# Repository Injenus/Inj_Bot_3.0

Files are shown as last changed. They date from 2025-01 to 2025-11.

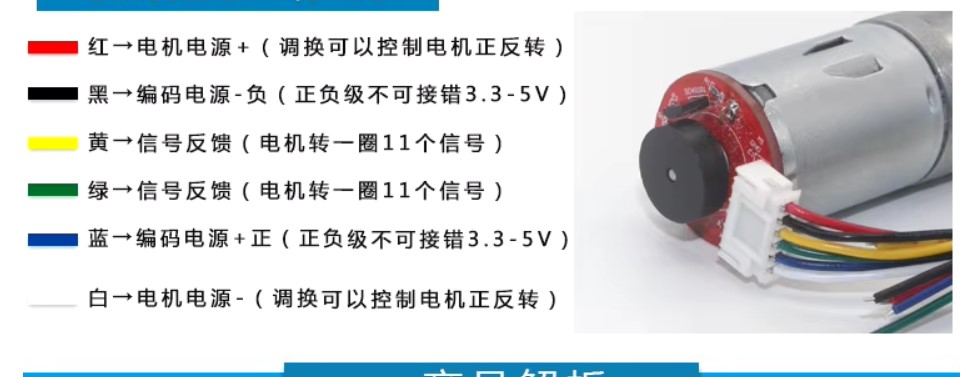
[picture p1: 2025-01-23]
chinese_motor.jpg

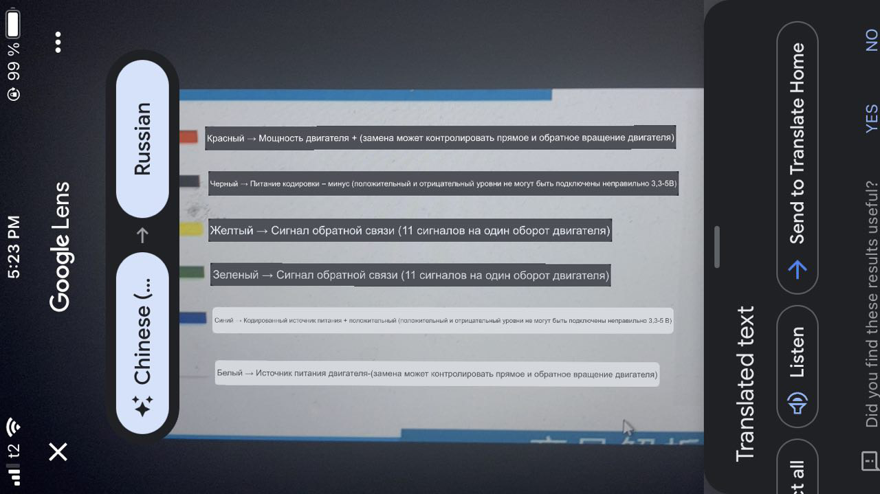
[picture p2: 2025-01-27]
trans_chinese_motor.jpg

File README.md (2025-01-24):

## Автономоный мобильный робот Inj Bot 3.0

### Имеет:
- ~~всех;~~
- манипулятор с 4-я степенями свободы;
- основную бинокулярную камеру с двумя степенями свободы;
- вспомогательную камеру на схвате манипулятора;
- лидар с регулируемой плоскостью положения;
- 7" экран для взаимодействия с человеком.<br/><br/>
### Фичи:
- Все вычисления производятся на борту согласно заложенной задаче.
- Запас хода не менее  минут, в среднем около  часов, в режиме ожидания - до  часов.<br/><br/>

### Железо:
- Raspberry Pi 5 с TPU ускорителем Google Coral.
- STM32F401 в качестве драйвера двигателей.
- Arduino Nano в качестве драйвера манипулятора.<br/><br/>

### Софт:
- ROS2.
- Кастомные пакеты для управления скоростью движения робота, положением манипулятора, обработке данных лидара и камер.

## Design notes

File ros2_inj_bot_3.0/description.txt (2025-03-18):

1. Пакет взаимодейсвтия с драйвером сервоприводов (servo):
    - отправка в ком-порт (send_com) данных из топика servo/to_write
    - получение из ком-порта (receive_com) и публикация в топик servo/current

2. Пакет взаимодейсвтия с камерами (camera):
    - получение потока с бинокулярной камеры (binocular_cam) и публикация в топик cam/binocular
    - получение потока с камеры на манипултяоре (arm_cam) и публикация в топик cam/arm

3. Пакет взаимодейсвтия с колёсами (wheel):
    - получение текущих об/мин с каждого колеса и публикация в топик wheel/current_rpm
    - чтение из топика wheel/target_rpm (об/мин) и отправка в ком-порт
        (получение и чтение данных реализовано в одном узле data_exchange - используется один uart канал)
            - для линейных и угловыйх скоростей используем стандратным протокол Twist,
            для обычных колёс имеем целевую линейную скрость и угловую по вепртикальной оси,
            которая представлет собой просто результат ПИДа по текущей ошибке
            - контроль об/мин колёс происходит на драйвере, но инф-цию об актуальных об/мин всё равно переылаем

4. Пакет для rplidar от разарботчиков (sllidar_ros2):
    - получение данных от лидара (rplidar c1) и публикация их в топик /scan

5. Пакет обработки данных лидара (lidar):
    - чтение данных из топика /scan
    - формирование моментальной карты, обработка зон интереса, публикация в топик lidar 
        (get_main_obstacles публикует медианные расстояния по заданному размеру сектора окружности)

6. Пакет для работы моделей ML (coral):
    - a hihuya tut ne budet, huy nastriosh ebuchiy coral

7. Пакет для ручного управления роботом (keyboard):
    - соотвутствующие узлы формируют уставки для колёс и целевые обобщённые координаты для камеры и маниулятора соответственно

8 - .. Пакеты для конкретных миссий.

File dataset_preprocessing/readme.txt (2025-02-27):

Аргументы cmd:
parser = argparse.ArgumentParser()
parser.add_argument("--src_dir", type=str, default="src_data", help="Исходная папка с данными")
parser.add_argument("--output_dir", type=str, default="augmented_data", help="Выходная папка")
parser.add_argument("--start_idx", type=int, default=0, help="Начальный индекс изображений")
parser.add_argument("--end_idx", type=int, default=None, help="Конечный индекс изображений")
args = parser.parse_args()

python run.py --src_dir src_data --output_dir augmented_data --start_idx 0 --end_idx 100

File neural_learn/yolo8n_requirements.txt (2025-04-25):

# Основные пакеты YOLO
ultralytics
torch
torchvision

# Обработка данных и изображений
numpy
pandas
opencv-python
Pillow
scikit-learn
scipy
imageio

# Визуализация и логирование
matplotlib
seaborn
tqdm

# Форматы данных и сериализация
PyYAML
tensorflow  # Для экспорта в TFLite

# Системные утилиты
psutil
py-cpuinfo
python-dotenv

# Сетевые и дополнительные зависимости
requests
prettytable
boto3
pandas-stubs

# Скрытые зависимости YOLO
pyqt5 # Для GUI
lap  # Для трекинга
thop  # Для FLOPs подсчета
triton  # Для некоторых оптимизаций
onnx  # Для экспорта моделей
onnxruntime  # Для инференса
protobuf # Для сериализации

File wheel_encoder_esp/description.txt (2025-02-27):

От контроллера (фактические скорости):
<S><speed_f_l><speed_f_l><speed_f_l><speed_f_l><speed_b_l><speed_b_l><speed_b_l><speed_b_l><speed_f_r><speed_f_r><speed_f_r><speed_f_r><speed_b_r><speed_b_r><speed_b_r><speed_b_r><SUM><SUM>
Последовательность сообщения:
    символ S
    4 байта float для скорости левого переднего колеса
    4 байта float для скорости левого заднего колеса
    4 байта float для скорости правого переднего колеса
    4 байта float для скорости правого заднего колеса
    2 байта контрольной суммы Флетчер-16

От хоста (целевые скорости):
<S><speed_f_l><speed_f_l><speed_f_l><speed_f_l><speed_b_l><speed_b_l><speed_b_l><speed_b_l><speed_f_r><speed_f_r><speed_f_r><speed_f_r><speed_b_r><speed_b_r><speed_b_r><speed_b_r><SUM><SUM>
Последовательность сообщения:
    символ S
    4 байта float для скорости левого переднего колеса
    4 байта float для скорости левого заднего колеса
    4 байта float для скорости правого переднего колеса
    4 байта float для скорости правого заднего колеса
    2 байта контрольной суммы Флетчер-16

отлично, теперь напиши для этого кода, чтобы он выводил в сериал не строку, а сами байты согласно протоколу:
<S><speed_f_l><speed_1><speed_1><speed_1><speed_1><speed_2><speed_2><speed_2><speed_2><speed_3><speed_3><speed_3><speed_3><speed_4><speed_4><speed_4><SUM><SUM>
Последовательность сообщения:
    символ S
    4 байта float для скорости левого переднего колеса
    4 байта float для скорости левого заднего колеса
    4 байта float для скорости правого переднего колеса
    4 байта float для скорости правого заднего колеса
    2 байта контрольной суммы Флетчер-16

да, нужно добавить вычисление конторльной суммы - для ВСЕХ байт до ней (включая и первый символ S)

здорово

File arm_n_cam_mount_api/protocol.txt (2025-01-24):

<A><angle0><angle0><angle1><angle1><angle2><angle2><angle3><angle3><angle4><angle4><angle5><angle5><angle6><angle6><SUM><SUM>

первым идёт байт - ascii-символ A, 

затем 14 байт углов для каждой сервы (по два байта на одну серву, диапазон от 0 до 270),
	первые 5 - рука снизу вверх, послдение 2 - камера снизу вверх

затем двухбайтовая контрольная сумма всех байт (15 байт) по формуле Флетчер-16

Подробнее про порядок серв:
	0 - вращат. основание руки
	1 - нижнее звено руки
	2 - среднее звено руки
	3 - верхнее звено руки
	4 - схват руки
	5 - вращат. основание камеры
	6 - звено камеры

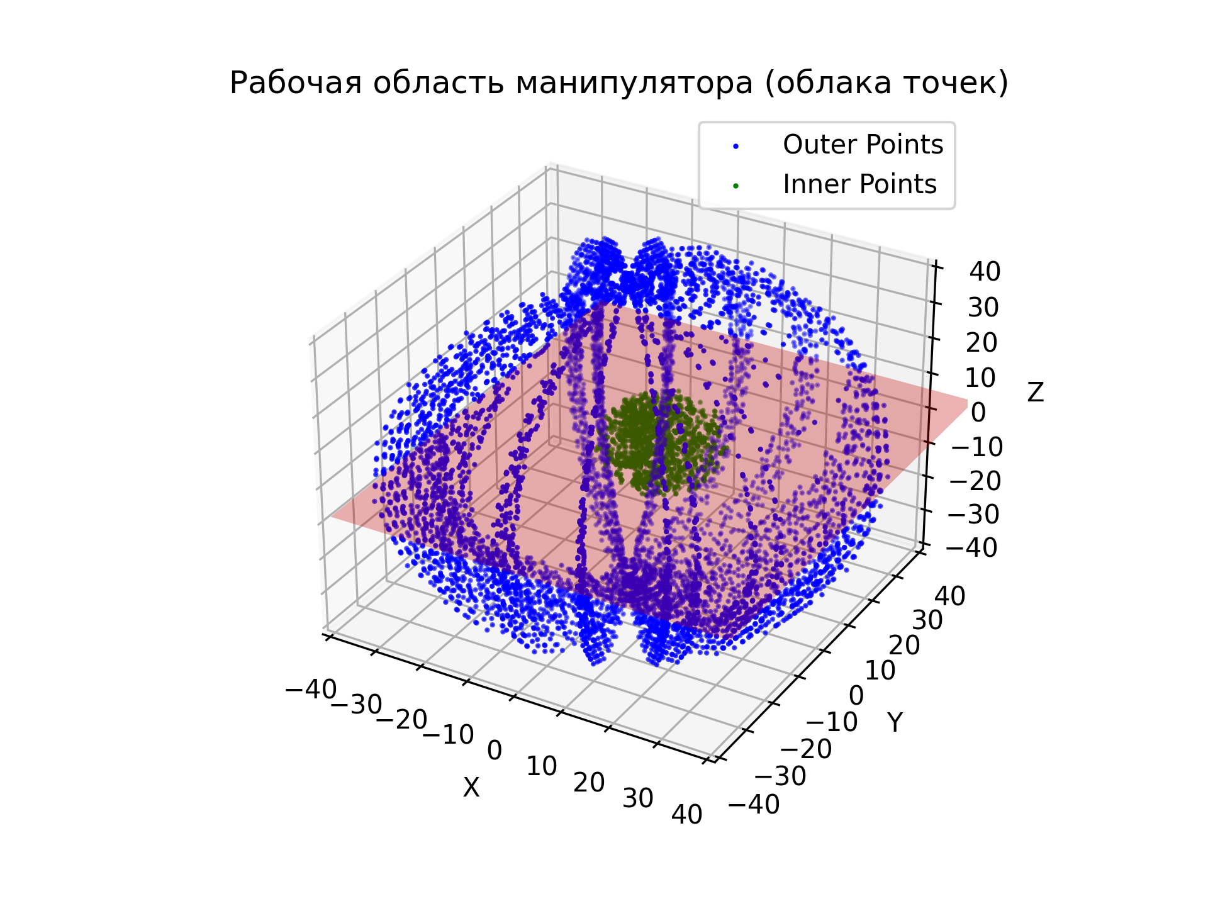
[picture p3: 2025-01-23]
manipulator_view/workspace_points_9.png

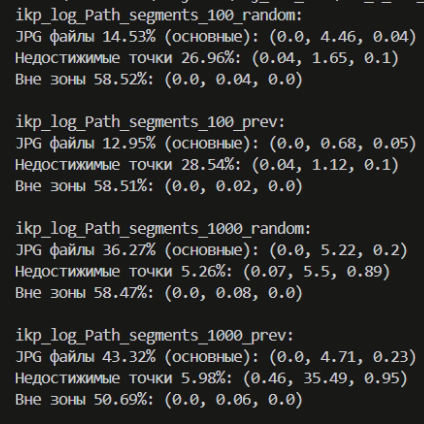
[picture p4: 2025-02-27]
arm_n_cam_mount_api_8_bytes/ikp_log.png

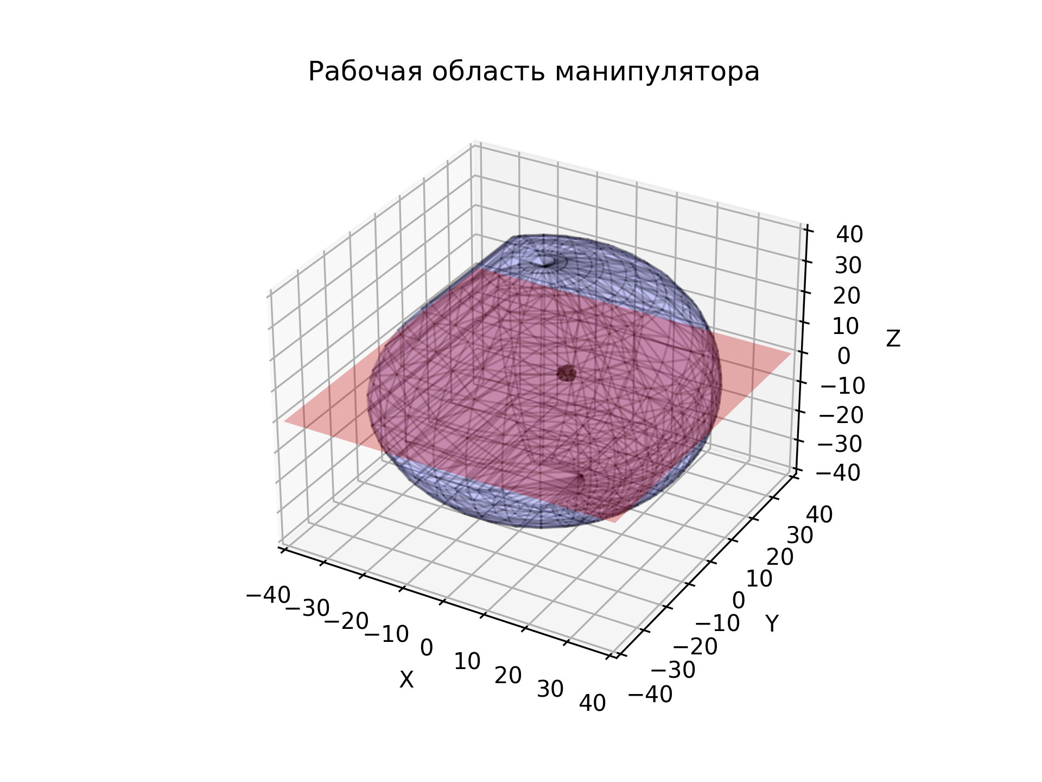
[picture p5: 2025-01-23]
manipulator_view/workspace_polygs_4.png

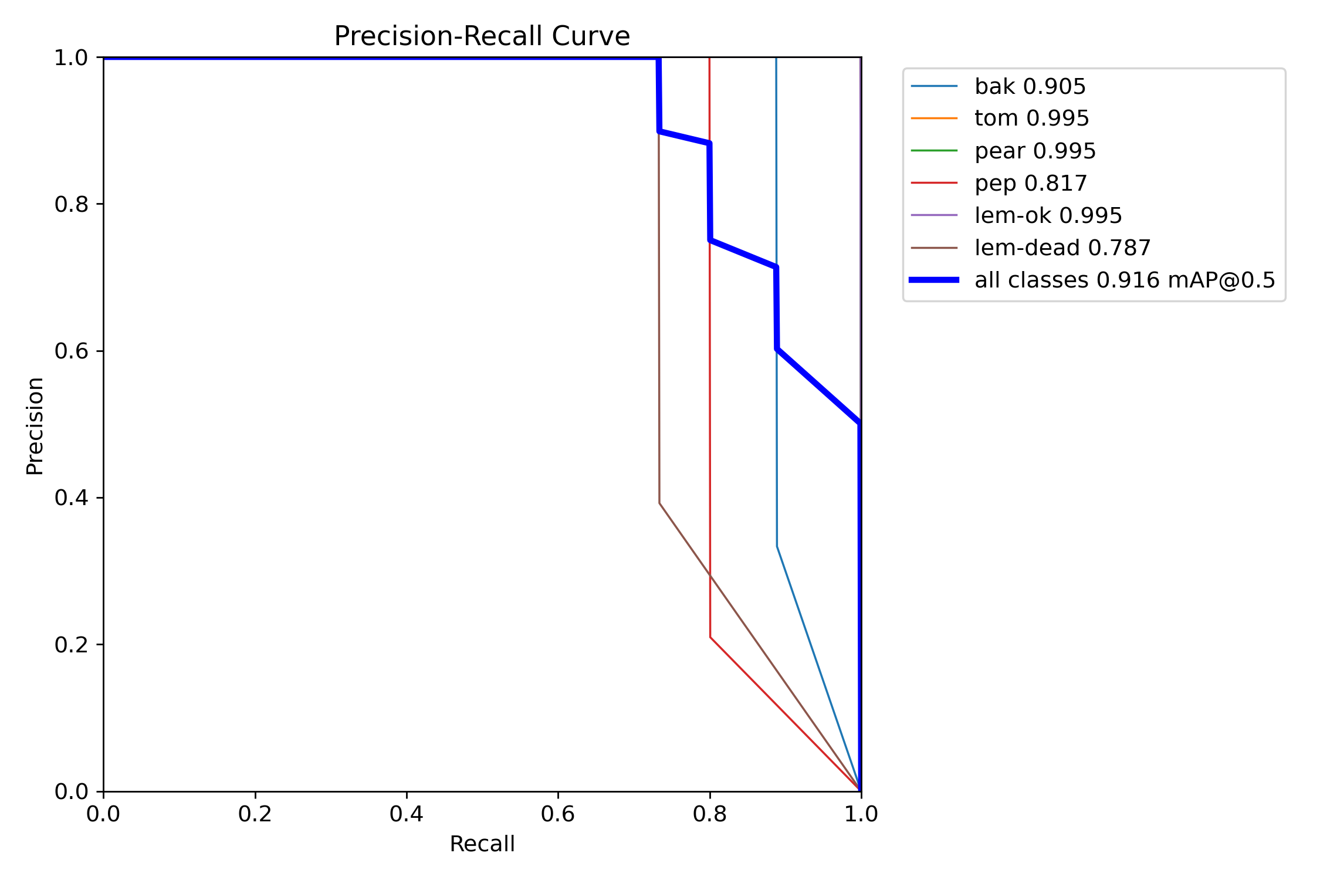
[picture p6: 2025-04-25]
neural_learn/runs/detect/fruit_detector/PR_curve.png

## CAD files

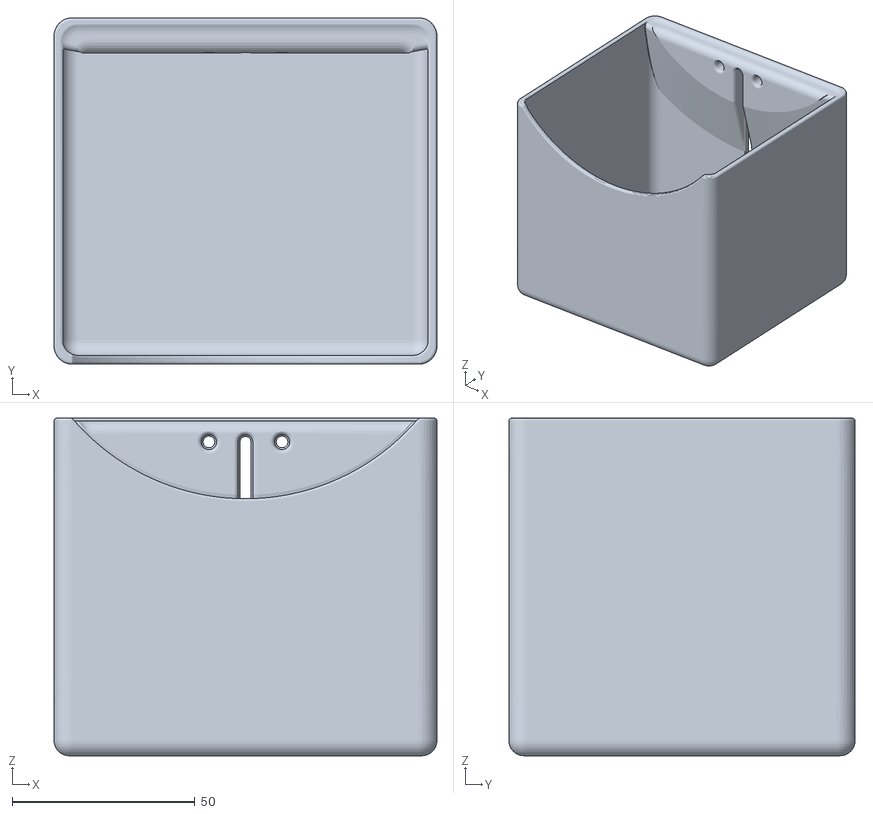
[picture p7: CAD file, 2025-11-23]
bot_parts/box_maxi_reinforced.stl
104.8 x 94.8 x 92.4

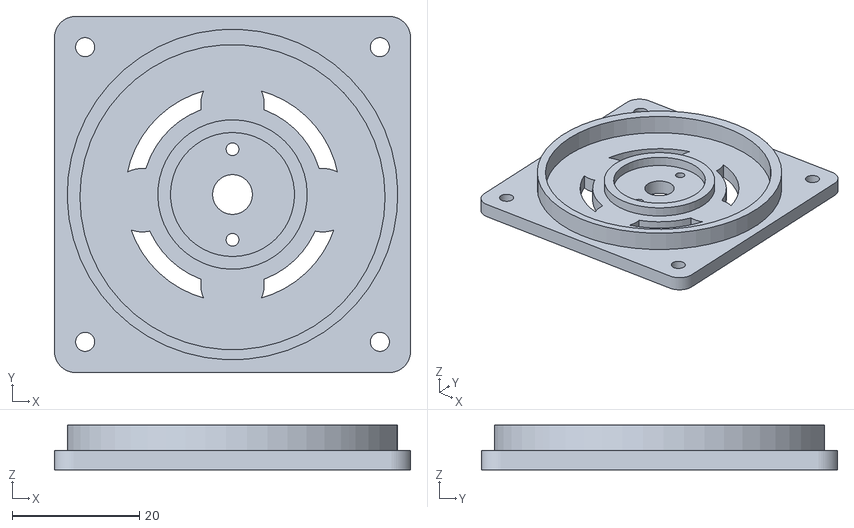
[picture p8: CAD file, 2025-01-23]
servo_cam_mount/base.stl
56.0 x 56.0 x 7.00

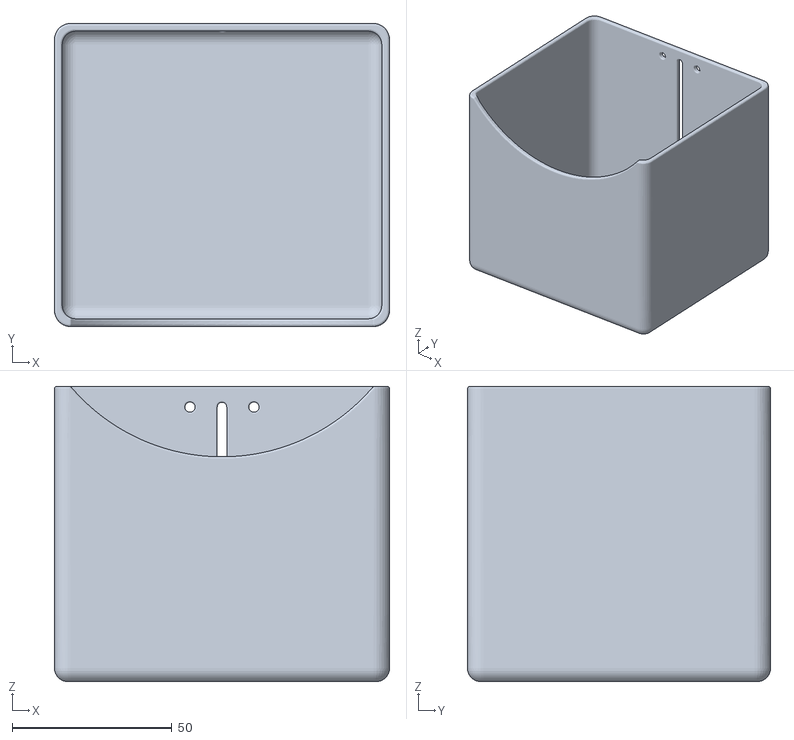
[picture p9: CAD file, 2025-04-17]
bot_parts/box_maxi_stable.stl
104.8 x 94.8 x 92.4

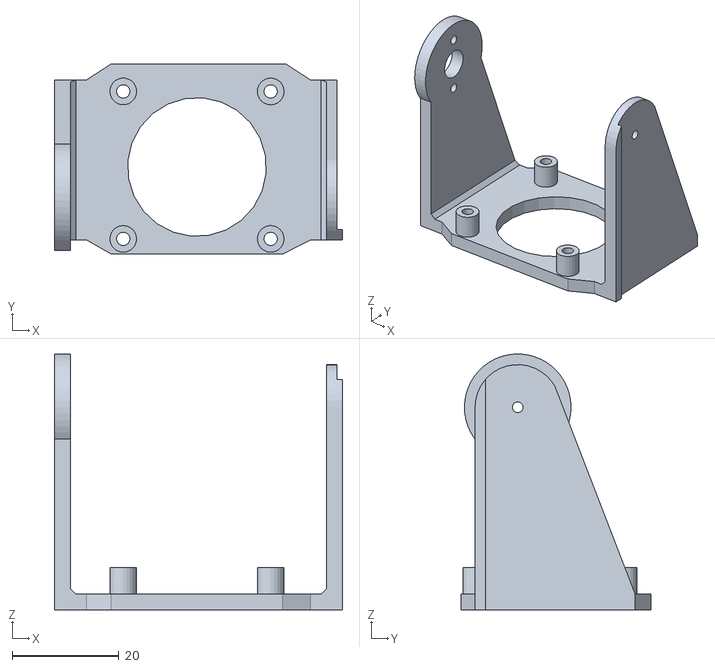
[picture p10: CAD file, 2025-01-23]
servo_cam_mount/camera_mount.stl
54.0 x 35.6 x 48.0

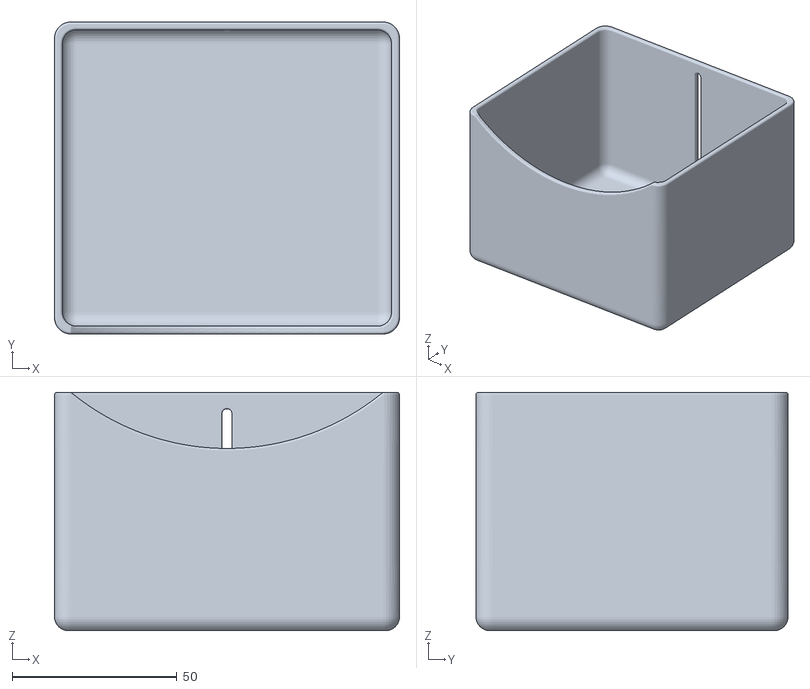
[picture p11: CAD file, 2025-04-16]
bot_parts/box_mini.stl
104.8 x 94.8 x 72.4

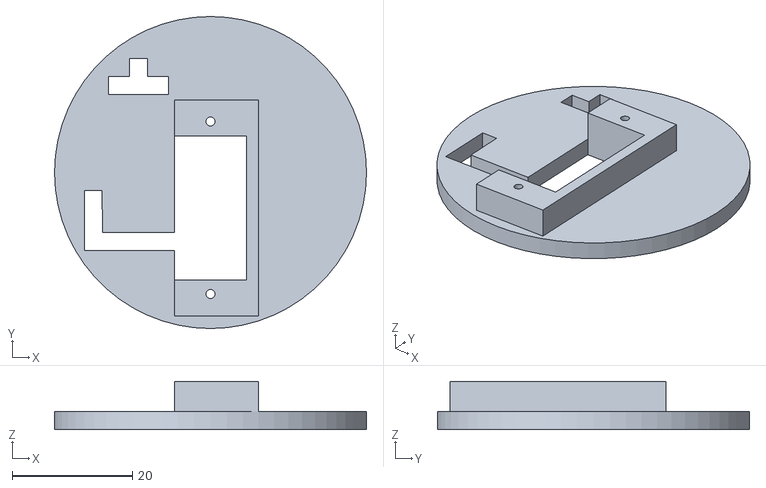
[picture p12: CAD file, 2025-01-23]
servo_cam_mount/Ring.stl
52.0 x 52.0 x 8.00

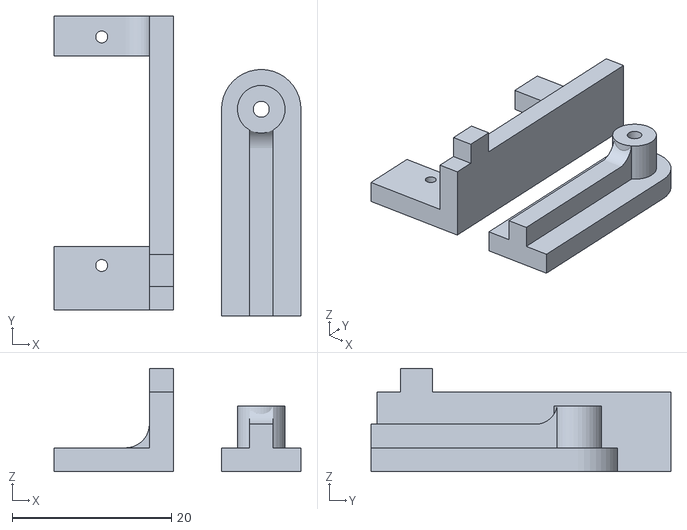
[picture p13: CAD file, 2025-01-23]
servo_cam_mount/brackets.stl
31.1 x 37.7 x 13.0

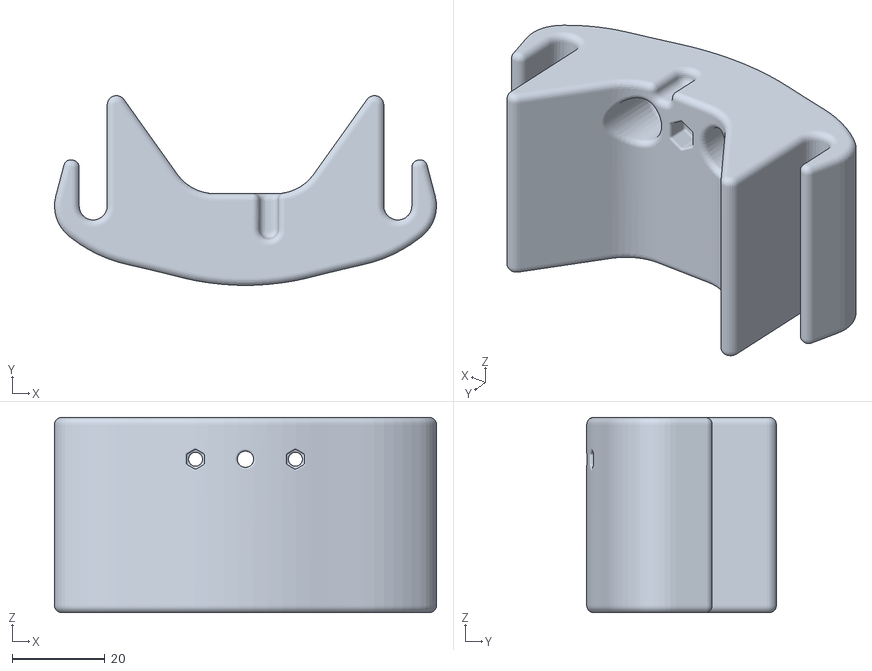
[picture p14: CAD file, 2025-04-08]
bot_parts/magnets.stl
82.2 x 40.9 x 42.0

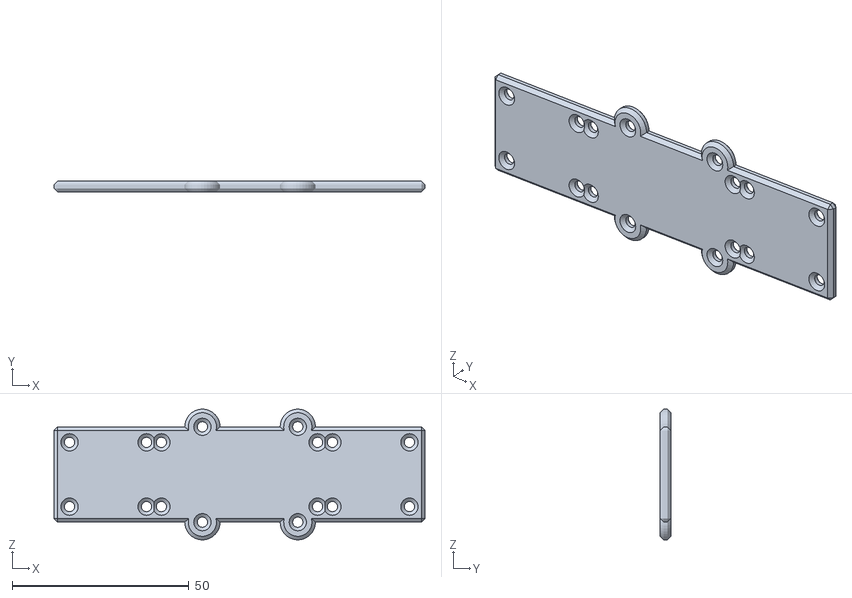
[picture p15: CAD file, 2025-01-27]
bot_parts/bin_cam.stl
105.0 x 3.00 x 37.0

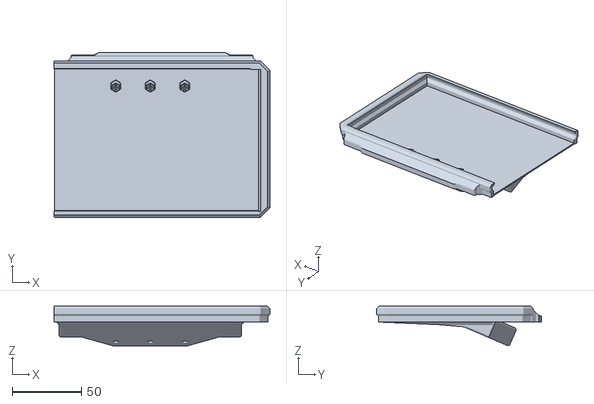
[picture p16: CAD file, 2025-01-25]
bot_parts/display.stl
156.5 x 119.4 x 28.7

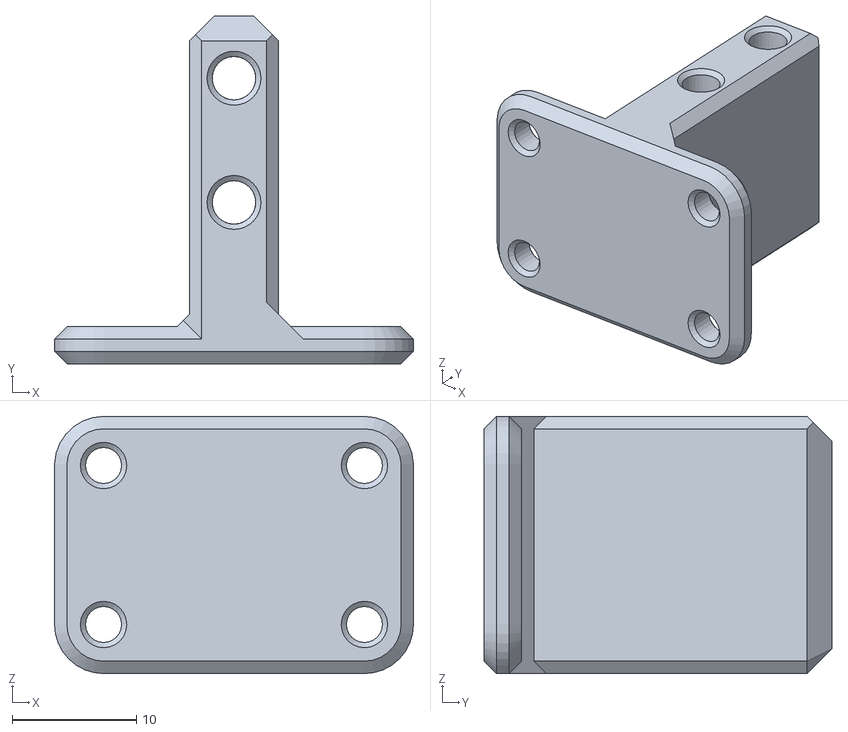
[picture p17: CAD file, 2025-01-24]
bot_parts/arm_cam.stl
28.9 x 28.0 x 20.7

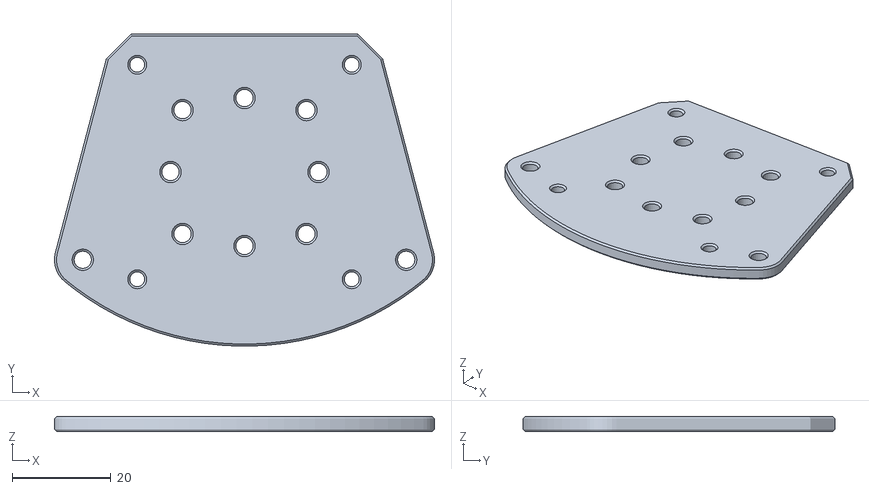
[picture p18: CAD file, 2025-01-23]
bot_parts/lidar.stl
77.0 x 63.3 x 3.00

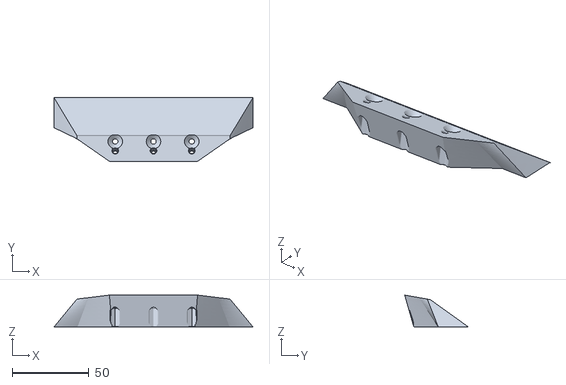
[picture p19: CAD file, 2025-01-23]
bot_parts/adapter.stl
130.0 x 41.6 x 20.8

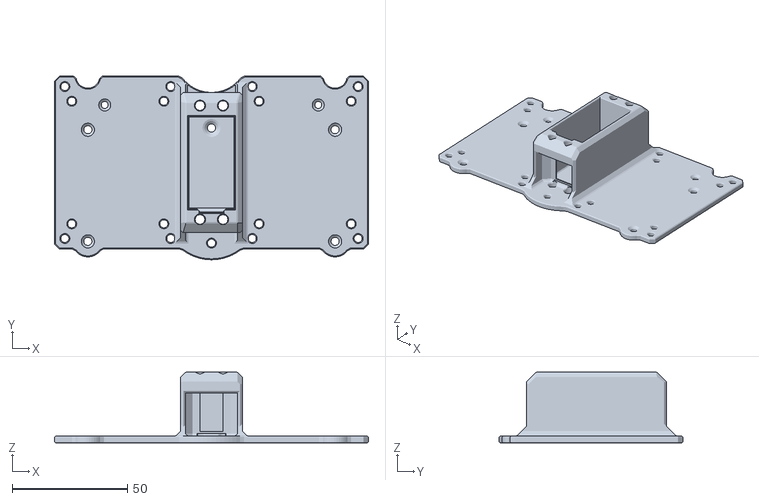
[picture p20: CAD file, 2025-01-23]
bot_parts/arm.stl
136.4 x 79.8 x 30.8

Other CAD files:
bot_parts/box_maxi.stl
bot_parts/body.stl
bot_parts/stm.stl
bot_parts/display_test.stl
bot_parts/rpi.stl

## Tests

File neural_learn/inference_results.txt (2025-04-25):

bak-ok-9103.jpg: 224x224 1 bak, 6.5ms
Speed: 1.4ms preprocess, 6.5ms inference, 0.9ms postprocess per image at shape (1, 3, 224, 224)
Class ID: 0, Name: bak, Confidence: 0.97

bak-ok-9110.jpg: 224x224 1 bak, 5.3ms
Speed: 0.4ms preprocess, 5.3ms inference, 0.6ms postprocess per image at shape (1, 3, 224, 224)
Class ID: 0, Name: bak, Confidence: 0.96

bak-ok-9144.jpg: 224x224 1 bak, 5.4ms
Speed: 0.4ms preprocess, 5.4ms inference, 0.6ms postprocess per image at shape (1, 3, 224, 224)
Class ID: 0, Name: bak, Confidence: 0.96

bak-ok-9154.jpg: 224x224 1 bak, 5.7ms
Speed: 0.4ms preprocess, 5.7ms inference, 0.7ms postprocess per image at shape (1, 3, 224, 224)
Class ID: 0, Name: bak, Confidence: 0.96

lem-dead-9269.jpg: 224x224 1 lem-dead, 5.3ms
Speed: 0.4ms preprocess, 5.3ms inference, 0.6ms postprocess per image at shape (1, 3, 224, 224)
Class ID: 5, Name: lem-dead, Confidence: 0.96

lem-dead-9272.jpg: 224x224 1 lem-dead, 6.1ms
Speed: 0.4ms preprocess, 6.1ms inference, 0.6ms postprocess per image at shape (1, 3, 224, 224)
Class ID: 5, Name: lem-dead, Confidence: 0.96

lem-dead-9274.jpg: 224x224 1 lem-dead, 5.2ms
Speed: 0.4ms preprocess, 5.2ms inference, 0.6ms postprocess per image at shape (1, 3, 224, 224)
Class ID: 5, Name: lem-dead, Confidence: 0.96

lem-dead-9282.jpg: 224x224 1 lem-dead, 5.3ms
Speed: 0.4ms preprocess, 5.3ms inference, 0.6ms postprocess per image at shape (1, 3, 224, 224)
Class ID: 5, Name: lem-dead, Confidence: 0.95

lem-dead-9285.jpg: 224x224 1 lem-dead, 5.3ms
Speed: 0.4ms preprocess, 5.3ms inference, 0.6ms postprocess per image at shape (1, 3, 224, 224)
Class ID: 5, Name: lem-dead, Confidence: 0.92

lem-dead-9305.jpg: 224x224 1 lem-dead, 5.3ms
Speed: 0.4ms preprocess, 5.3ms inference, 0.6ms postprocess per image at shape (1, 3, 224, 224)
Class ID: 5, Name: lem-dead, Confidence: 0.93

lem-dead-9313.jpg: 224x224 1 lem-dead, 5.4ms
Speed: 0.4ms preprocess, 5.4ms inference, 0.6ms postprocess per image at shape (1, 3, 224, 224)
Class ID: 5, Name: lem-dead, Confidence: 0.94

lem-dead-9346.jpg: 224x224 1 lem-dead, 5.5ms
Speed: 0.4ms preprocess, 5.5ms inference, 0.6ms postprocess per image at shape (1, 3, 224, 224)
Class ID: 5, Name: lem-dead, Confidence: 0.95

lem-ok-8700.jpg: 224x224 1 lem-ok, 5.4ms
Speed: 0.4ms preprocess, 5.4ms inference, 0.6ms postprocess per image at shape (1, 3, 224, 224)
Class ID: 4, Name: lem-ok, Confidence: 0.96

lem-ok-8706.jpg: 224x224 1 lem-ok, 5.4ms
Speed: 0.4ms preprocess, 5.4ms inference, 0.6ms postprocess per image at shape (1, 3, 224, 224)
Class ID: 4, Name: lem-ok, Confidence: 0.98

lem-ok-8710.jpg: 224x224 1 lem-ok, 5.3ms
Speed: 0.4ms preprocess, 5.3ms inference, 0.6ms postprocess per image at shape (1, 3, 224, 224)
Class ID: 4, Name: lem-ok, Confidence: 0.97

lem-ok-8718.jpg: 224x224 1 lem-ok, 5.3ms
Speed: 0.4ms preprocess, 5.3ms inference, 0.6ms postprocess per image at shape (1, 3, 224, 224)
Class ID: 4, Name: lem-ok, Confidence: 0.95

lem-ok-9233.jpg: 224x224 1 lem-ok, 5.4ms
Speed: 0.4ms preprocess, 5.4ms inference, 0.6ms postprocess per image at shape (1, 3, 224, 224)
Class ID: 4, Name: lem-ok, Confidence: 0.97

pear-8784.jpg: 224x224 1 pear, 5.3ms
Speed: 0.4ms preprocess, 5.3ms inference, 0.6ms postprocess per image at shape (1, 3, 224, 224)
Class ID: 2, Name: pear, Confidence: 0.98

pear-8787.jpg: 224x224 1 pear, 5.3ms
Speed: 0.4ms preprocess, 5.3ms inference, 0.6ms postprocess per image at shape (1, 3, 224, 224)
Class ID: 2, Name: pear, Confidence: 0.99

pear-8802.jpg: 224x224 1 pear, 5.7ms
Speed: 0.4ms preprocess, 5.7ms inference, 0.6ms postprocess per image at shape (1, 3, 224, 224)
Class ID: 2, Name: pear, Confidence: 0.98

pear-8807.jpg: 224x224 1 pear, 5.4ms
Speed: 0.4ms preprocess, 5.4ms inference, 0.6ms postprocess per image at shape (1, 3, 224, 224)
Class ID: 2, Name: pear, Confidence: 0.98

pear-8812.jpg: 224x224 1 pear, 5.6ms
Speed: 0.4ms preprocess, 5.6ms inference, 0.6ms postprocess per image at shape (1, 3, 224, 224)
Class ID: 2, Name: pear, Confidence: 0.98

pear-8813.jpg: 224x224 1 pear, 6.8ms
Speed: 0.4ms preprocess, 6.8ms inference, 0.7ms postprocess per image at shape (1, 3, 224, 224)
Class ID: 2, Name: pear, Confidence: 0.97

pear-8814.jpg: 224x224 1 pear, 5.9ms
Speed: 0.4ms preprocess, 5.9ms inference, 0.6ms postprocess per image at shape (1, 3, 224, 224)
Class ID: 2, Name: pear, Confidence: 0.99

pear-8820.jpg: 224x224 1 pear, 5.7ms
Speed: 0.4ms preprocess, 5.7ms inference, 0.6ms postprocess per image at shape (1, 3, 224, 224)
Class ID: 2, Name: pear, Confidence: 0.98

pear-8827.jpg: 224x224 1 pear, 6.1ms
Speed: 0.4ms preprocess, 6.1ms inference, 0.6ms postprocess per image at shape (1, 3, 224, 224)
Class ID: 2, Name: pear, Confidence: 0.98

pear-8851.jpg: 224x224 1 pear, 5.7ms
Speed: 0.4ms preprocess, 5.7ms inference, 1.1ms postprocess per image at shape (1, 3, 224, 224)
Class ID: 2, Name: pear, Confidence: 0.99

pear-8856.jpg: 224x224 1 pear, 5.8ms
Speed: 0.4ms preprocess, 5.8ms inference, 0.6ms postprocess per image at shape (1, 3, 224, 224)
Class ID: 2, Name: pear, Confidence: 0.99

pep-9051.jpg: 224x224 1 pep, 5.7ms
Speed: 0.4ms preprocess, 5.7ms inference, 0.7ms postprocess per image at shape (1, 3, 224, 224)
Class ID: 3, Name: pep, Confidence: 0.99

pep-9061.jpg: 224x224 1 pep, 6.0ms
Speed: 0.4ms preprocess, 6.0ms inference, 0.6ms postprocess per image at shape (1, 3, 224, 224)
Class ID: 3, Name: pep, Confidence: 0.99

pep-9077.jpg: 224x224 1 pep, 6.9ms
Speed: 0.4ms preprocess, 6.9ms inference, 0.8ms postprocess per image at shape (1, 3, 224, 224)
Class ID: 3, Name: pep, Confidence: 0.97

pep-9079.jpg: 224x224 1 pep, 6.9ms
Speed: 0.6ms preprocess, 6.9ms inference, 0.8ms postprocess per image at shape (1, 3, 224, 224)
Class ID: 3, Name: pep, Confidence: 0.97

pep-9082.jpg: 224x224 1 pep, 6.7ms
Speed: 0.6ms preprocess, 6.7ms inference, 0.8ms postprocess per image at shape (1, 3, 224, 224)
Class ID: 3, Name: pep, Confidence: 0.97

pep-9087.jpg: 224x224 1 pep, 6.9ms
Speed: 0.6ms preprocess, 6.9ms inference, 0.8ms postprocess per image at shape (1, 3, 224, 224)
Class ID: 3, Name: pep, Confidence: 0.97

pep-9091.jpg: 224x224 1 pep, 6.8ms
Speed: 0.6ms preprocess, 6.8ms inference, 0.8ms postprocess per image at shape (1, 3, 224, 224)
Class ID: 3, Name: pep, Confidence: 0.97

tom-ok-8907.jpg: 224x224 1 tom, 7.1ms
Speed: 0.5ms preprocess, 7.1ms inference, 0.8ms postprocess per image at shape (1, 3, 224, 224)
Class ID: 1, Name: tom, Confidence: 0.96

tom-ok-8912.jpg: 224x224 1 tom, 7.1ms
Speed: 0.6ms preprocess, 7.1ms inference, 0.9ms postprocess per image at shape (1, 3, 224, 224)
Class ID: 1, Name: tom, Confidence: 0.99

tom-ok-8913.jpg: 224x224 1 tom, 7.2ms
Speed: 0.6ms preprocess, 7.2ms inference, 0.8ms postprocess per image at shape (1, 3, 224, 224)
Class ID: 1, Name: tom, Confidence: 0.99

tom-ok-8919.jpg: 224x224 1 tom, 6.0ms
Speed: 0.5ms preprocess, 6.0ms inference, 0.8ms postprocess per image at shape (1, 3, 224, 224)
Class ID: 1, Name: tom, Confidence: 0.99

tom-ok-8940.jpg: 224x224 1 tom, 6.4ms
Speed: 0.5ms preprocess, 6.4ms inference, 0.8ms postprocess per image at shape (1, 3, 224, 224)
Class ID: 1, Name: tom, Confidence: 0.99

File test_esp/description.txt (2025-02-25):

I колесо - верхнее правое (I квадрант)
II колесо - верхнее левое (II квадрант)
III колесо - нижнее левое (III квадрант)
IV колесо - нижнее правое (IV квадрант)

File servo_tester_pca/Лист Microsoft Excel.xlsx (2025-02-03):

x | 0 | 225 |  | 0 | 45 | 135 | 180 | 225 | 270
y | 100 | 490 |  | 100 | 178 | 334 | 412 | 490 | 568
k | 1.733333333
m | 100
 | 0 | 1 | 2 | 3 | 4 |  | 5 | 6
min | 84 | 112 | 110(coll) | 106(coll) | 251 |  | 135 | 150
middle | 333 | 326 | 326 | 326 | _396_ |  | 335 | _416_
max | 589 | 536 (coll) | 546(coll) | 542(coll) | 440 |  | 535 | 467
delta fro middle | 249 | 210 | 216 | 216 | -----
принятые дипазоны
0 серва | 84 | 582 |  | 0 | 2…
1-4 серва | 116 | 542 |  | 0 | 2…
схват | 251 | 440 |  | - | -
5 | 135 | 525 |  | 0 | 1....
6 | 150 | 467 |  | 0 | 1....

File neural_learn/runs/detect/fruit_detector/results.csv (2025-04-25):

epoch | time | train/box_loss | train/cls_loss | train/dfl_loss | metrics/precision(B) | metrics/recall(B) | metrics/mAP50(B) | metrics/mAP50-95(B) | val/box_loss | val/cls_loss | val/dfl_loss | lr/pg0 | lr/pg1 | lr/pg2
1 | 11.5171 | 0.71971 | 3.6472 | 0.93587 | 0.00443 | 0.6912 | 0.20344 | 0.14742 | 0.56975 | 3.69282 | 0.81918 | 0.00019 | 0.00019 | 0.00019
2 | 22.5634 | 0.7128 | 2.15803 | 0.93619 | 0.90334 | 0.19842 | 0.44088 | 0.33794 | 0.62274 | 3.08879 | 0.82883 | 0.000386139 | 0.000386139 | 0.000386139
3 | 33.63 | 0.67493 | 1.34569 | 0.91846 | 0.92647 | 0.38148 | 0.83576 | 0.71699 | 0.55883 | 2.30239 | 0.86926 | 0.000578318 | 0.000578318 | 0.000578318
4 | 44.7428 | 0.6374 | 1.02427 | 0.93516 | 0.9485 | 0.4037 | 0.86658 | 0.74595 | 0.57052 | 1.90605 | 0.88298 | 0.000766537 | 0.000766537 | 0.000766537
5 | 55.7914 | 0.65385 | 0.90377 | 0.92327 | 0.86304 | 0.85377 | 0.8498 | 0.75112 | 0.5777 | 1.25715 | 0.90867 | 0.000950796 | 0.000950796 | 0.000950796
6 | 69.2669 | 0.66827 | 0.90189 | 0.95978 | 0.87382 | 0.89263 | 0.87536 | 0.78223 | 0.54078 | 0.94276 | 0.89411 | 0.0009505 | 0.0009505 | 0.0009505
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

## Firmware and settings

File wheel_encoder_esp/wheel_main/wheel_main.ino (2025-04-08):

#include <Arduino.h>

// Конфигурационные константы
#define RPM_MULTIPLIER 8192
#define REGULATOR_MODE 0        // 0 - simple P, 1 - PID
#define ENCODER_STEPS_PER_REVOLUTION 2343 // Шагов энкодера на один оборот
#define ENCODER_STEPS_DIVIDER 10
#define UPDATE_INTERVAL_MS 4              // Интервал обновления в миллисекундах
#define NUMBER_OF_ENCODERS 4               // Количество энкодеров
#define DATA_PACKET_SIZE 19                // Размер пакета данных в байтах
#define PWM_FREQUENCY 16000                // Частота ШИМ в Гц
#define PWM_RESOLUTION_BITS 12             // Разрешение ШИМ (макс. значение 4095)
#define MAX_PWM_VALUE 4095                 // Максимальное значение ШИМ
#define PWM_DEADZONE 42                // Зона нечувствительности регулятора

// Пины подключения энкодеров [A, B]
const uint8_t ENCODER_PINS[4][2] = {
  {2, 15},  // Энкодер 1
  {27, 14}, // Энкодер 2
  {32, 33}, // Энкодер 3
  {26, 25}  // Энкодер 4
};

// Пины управления моторами [A, B]
const uint8_t MOTOR_PINS[4][2] = {
  {16, 4},  // Мотор 1
  {17, 18}, // Мотор 2
  {21, 19}, // Мотор 3
  {22, 23}  // Мотор 4
};

// Структура для хранения состояния энкодера
struct Encoder {
  volatile int32_t step_count;    // Текущая позиция в шагах
  volatile uint8_t previous_state; // Предыдущее состояние контактов
};
volatile Encoder encoder_states[4]; // Массив энкодеров

// Структура для управления мотором
struct Motor {
  uint8_t pwm_channel_a;    // Номер канала ШИМ для выхода A
  uint8_t pwm_channel_b;    // Номер канала ШИМ для выхода B
  int32_t current_pwm;        // Текущее значение ШИМ  | int???
  int32_t target_rpm;         // Целевая скорость вращения
  int32_t measured_rpm;       // Измеренная скорость вращения
  int32_t prev_rpm;           //предыдущая измеренная скорость (для реалзации фильтра)
};
Motor motor_controllers[4]; // Массив моторов

// Структура для хранения состояния регуляторов
struct RegulatorState {
    int32_t _integral;   // интегральная составляющая ПИД-регулятора
    int32_t prevError;  // Предыдущая ошибка
    int32_t max_integral = RPM_MULTIPLIER * 1024;
};
RegulatorState regStates[4];  // Отдельные состояния для каждого регулятора

// Глобальные переменные
int32_t KP = 10;
int32_t KI = 1;
int32_t KD = 4;

volatile int32_t target_rpms[4] = {0}; // Целевые скорости для моторов
uint8_t serial_buffer[DATA_PACKET_SIZE]; // Буфер для приема данных
uint8_t buffer_position = 0;           // Текущая позиция в буфере
bool receiving_packet = false;         // Флаг приема пакета
int32_t divider_p_gain = 2; // обратный коэффициент (на него делим) простого регулятора
int32_t d_gain = 64;
int32_t prev_error[4] = {0}; // предыдущая ошибека для пртсого регулятора

// Объявления функций
void handle_encoder_isr(uint8_t encoder_index);
void encoder1_isr() { handle_encoder_isr(0); }
void encoder2_isr() { handle_encoder_isr(1); }
void encoder3_isr() { handle_encoder_isr(2); }
void encoder4_isr() { handle_encoder_isr(3); }
void setup_encoders();
void calculate_motor_speeds();
void send_serial_data();
bool process_data_packet();
uint16_t calculate_checksum(uint8_t* data, uint8_t length);
void update_motor_power(uint8_t motor_index);
uint8_t get_real_motor_idx(uint8_t motor_index);
int32_t computeRegulator(RegulatorState* regStates, int32_t error, int32_t dt);

// Начальная настройка
void setup() {
  Serial.begin(115200); // Инициализация последовательного порта
  
  setup_encoders(); // Настройка энкодеров
  
  // Инициализация моторов
  motor_controllers[0].pwm_channel_a = MOTOR_PINS[0][0];
  motor_controllers[0].pwm_channel_b = MOTOR_PINS[0][1];
  
  motor_controllers[1].pwm_channel_a = MOTOR_PINS[1][0];
  motor_controllers[1].pwm_channel_b = MOTOR_PINS[1][1];
  
  motor_controllers[2].pwm_channel_a = MOTOR_PINS[2][0];
  motor_controllers[2].pwm_channel_b = MOTOR_PINS[2][1];
  
  motor_controllers[3].pwm_channel_a = MOTOR_PINS[3][0];
  motor_controllers[3].pwm_channel_b = MOTOR_PINS[3][1];
  
  for(uint8_t i=0; i<4; i++){
    ledcAttach(motor_controllers[i].pwm_channel_a, PWM_FREQUENCY, PWM_RESOLUTION_BITS);
    ledcWrite(motor_controllers[i].pwm_channel_a, 0);
    
    ledcAttach(motor_controllers[i].pwm_channel_b, PWM_FREQUENCY, PWM_RESOLUTION_BITS);
    ledcWrite(motor_controllers[i].pwm_channel_b, 0);

    motor_controllers[i].current_pwm = 0;
    motor_controllers[i].target_rpm = 0;
    motor_controllers[i].measured_rpm = 0;
  }
}

// Основной цикл программы
void loop() {
  static uint32_t last_update = 0;    // Время последнего обновления
  static uint32_t last_data_time = 0; // Время последнего приема данных

  // Прием данных с последовательного порта
  while(Serial.available() > 0){
    uint8_t _byte = Serial.read();
    last_data_time = millis();
    //Serial.println(_byte);
    
    if(_byte == 'S' && !receiving_packet){
      buffer_position = 0;
      serial_buffer[buffer_position] = _byte;
      buffer_position++;
      receiving_packet = true;
    }
    else if(receiving_packet && buffer_position < DATA_PACKET_SIZE){
      serial_buffer[buffer_position] = _byte;
      buffer_position++;
      
      if(buffer_position >= DATA_PACKET_SIZE){
        receiving_packet = false;
        if(process_data_packet()){
          // Успешно принятый пакет
        }
      }
    }
  }

  // Периодическое обновление системы
  if(millis() - last_update >= UPDATE_INTERVAL_MS){
    calculate_motor_speeds(); // Расчет текущих скоростей
    
    // Обновление целевых скоростей
    noInterrupts();
    for(uint8_t i=0; i<4; i++){
      motor_controllers[i].target_rpm = target_rpms[i];
    }
    interrupts();
    
    // Регулировка мощности моторов
    for(uint8_t i=0; i<4; i++){
      update_motor_power(i);
    }
    //update_motor_power(3);
    
    send_serial_data(); // Отправка данных
    last_update = millis();
  }

  // Сброс приема при простое
  if(receiving_packet && (millis() - last_data_time > 50)){
    receiving_packet = false;
  }
}

// Обработчик прерываний для энкодера
void handle_encoder_isr(uint8_t encoder_index) {
  // Чтение текущего состояния контактов
  uint8_t current_state = digitalRead(ENCODER_PINS[encoder_index][0]) << 1;
  current_state |= digitalRead(ENCODER_PINS[encoder_index][1]);
  
  // Определение направления вращения
  uint8_t state_change = (encoder_states[encoder_index].previous_state << 2) | current_state;
  const int8_t direction_table[] = {0,1,-1,0, -1,0,0,1, 1,0,0,-1, 0,-1,1,0};
  encoder_states[encoder_index].step_count += direction_table[state_change];
  
  encoder_states[encoder_index].previous_state = current_state; // Сохранение состояния
}

// Настройка энкодеров и прерываний
void setup_encoders() {
  for(uint8_t i=0; i<4; i++){
    // Настройка пинов как входы с подтяжкой
    pinMode(ENCODER_PINS[i][0], INPUT_PULLUP);
    pinMode(ENCODER_PINS[i][1], INPUT_PULLUP);
    
    // Инициализация начального состояния
    encoder_states[i].previous_state = digitalRead(ENCODER_PINS[i][0]) << 1;
    encoder_states[i].previous_state |= digitalRead(ENCODER_PINS[i][1]);
    
    // Назначение обработчиков прерываний
    switch(i){
      case 0:
        attachInterrupt(digitalPinToInterrupt(ENCODER_PINS[i][0]), encoder1_isr, CHANGE);
        attachInterrupt(digitalPinToInterrupt(ENCODER_PINS[i][1]), encoder1_isr, CHANGE);
        break;
      case 1:
        attachInterrupt(digitalPinToInterrupt(ENCODER_PINS[i][0]), encoder2_isr, CHANGE);
        attachInterrupt(digitalPinToInterrupt(ENCODER_PINS[i][1]), encoder2_isr, CHANGE);
        break;
      case 2:
        attachInterrupt(digitalPinToInterrupt(ENCODER_PINS[i][0]), encoder3_isr, CHANGE);
        attachInterrupt(digitalPinToInterrupt(ENCODER_PINS[i][1]), encoder3_isr, CHANGE);
        break;
      case 3:
        attachInterrupt(digitalPinToInterrupt(ENCODER_PINS[i][0]), encoder4_isr, CHANGE);
        attachInterrupt(digitalPinToInterrupt(ENCODER_PINS[i][1]), encoder4_isr, CHANGE);
        break;
    }
  }
}

// Расчет текущей скорости вращения
void calculate_motor_speeds() {
  static int32_t previous_steps[4] = {0}; // Предыдущие показания
  
  noInterrupts();
  for(uint8_t i=0; i<4; i++){
    int32_t steps = encoder_states[i].step_count - previous_steps[i];
    previous_steps[i] = encoder_states[i].step_count;
    
    // Расчет RPM: (шаги/обороты) * (миллисекунды в минуте / интервал)
    int32_t new_value = (RPM_MULTIPLIER * ENCODER_STEPS_DIVIDER * steps / ENCODER_STEPS_PER_REVOLUTION) * 3000;
    static uint8_t K = 4;
    motor_controllers[i].measured_rpm  = (motor_controllers[i].prev_rpm * ( (1 << K) - 1 ) + new_value) >> K;
    motor_controllers[i].prev_rpm = motor_controllers[i].measured_rpm;
    
  }
  interrupts();
}

// Функция для вывода массива байт в HEX
void printHex(uint8_t* data, size_t len) {
  for(size_t i = 0; i < len; i++) {
    if(data[i] < 0x10) Serial.print("0");
    Serial.print(data[i], HEX);
    Serial.print(" ");
  }
  Serial.println();
}

// Отправка данных через последовательный порт
void send_serial_data() {
  uint8_t output_packet[19] = {0}; // Инициализируем весь массив нулями
  output_packet[0] = 'S'; 
  
  // Запись значений RPM в пакет
  for(uint8_t i=0; i<4; i++){
    int32_t rpm_value = motor_controllers[i].measured_rpm;

    // Преобразуем в little-endian байты
    output_packet[1 + i*4] = (rpm_value)       & 0xFF; // Младший байт
    output_packet[2 + i*4] = (rpm_value >> 8)  & 0xFF;
    output_packet[3 + i*4] = (rpm_value >> 16) & 0xFF;
    output_packet[4 + i*4] = (rpm_value >> 24) & 0xFF; // Старший байт
  }
  
  // Расчет контрольной суммы (для 17 байт: 1 заголовок + 16 данных)
  uint16_t checksum = calculate_checksum(output_packet, 17);
  output_packet[17] = checksum >> 8;   // Старший байт контрольной суммы
  output_packet[18] = checksum & 0xFF; // Младший байт;
  
  Serial.write(output_packet, 19); // Отправка пакета
//  printHex(output_packet, 19);
//   for(uint8_t i=0; i<4; i++) {
//     int32_t rpm = *((int32_t*)&output_packet[1 + i*4]); // Для little-endian
//     Serial.print("RPM ");
//     Serial.print(i);
//     Serial.print(": ");
//     Serial.print((float)rpm/RPM_MULTIPLIER);
//     Serial.print("   ");
//   }
//   Serial.println();

}

// Обработка входящего пакета
bool process_data_packet() {
  // Проверка контрольной суммы
  uint16_t received_checksum = (serial_buffer[17] << 8) | serial_buffer[18];
  if(calculate_checksum(serial_buffer, 17) != received_checksum){
    return false;
  }

  // Чтение значений RPM
  noInterrupts();
  for(uint8_t i = 0; i < 4; i++) {
    // Создаем НЕ-volatile переменную для промежуточного копирования
    int32_t tmp;
    // Копируем 4 байта из serial_buffer (с учетом смещения, если нужно)
    memcpy(&tmp, &serial_buffer[1 + i * 4], sizeof(int32_t));
    // Присваиваем значение в volatile-массив
    target_rpms[i] = RPM_MULTIPLIER * tmp; // умнижаем рпм на местный коэффицент вычислений
  }
  interrupts();
  
  return true;
}

// Расчет контрольной суммы
uint16_t calculate_checksum(uint8_t* data, uint8_t length) {
  uint16_t sum1 = 0;
  uint16_t sum2 = 0;
  
  for(uint8_t i=0; i<length; i++){
    sum1 = (sum1 + data[i]) % 255;
    sum2 = (sum2 + sum1) % 255;
  }
  return (sum2 << 8) | sum1;
}

// Обновление мощности мотора
void update_motor_power(uint8_t motor_index) {

  bool flag_zero = false;
  int32_t error = motor_controllers[motor_index].target_rpm - 
                motor_controllers[motor_index].measured_rpm;

  if (motor_controllers[motor_index].target_rpm == 0){
    flag_zero = true;
  }

  if (REGULATOR_MODE == 0){
    // Пропорциональное регулирование
    int32_t pwm_change = (error / divider_p_gain + d_gain*(error-prev_error[motor_index])/UPDATE_INTERVAL_MS) / RPM_MULTIPLIER;
    prev_error[motor_index] = error;
    pwm_change = constrain(pwm_change, -420, 420);
    // Обновление значения PWM
    motor_controllers[motor_index].current_pwm += pwm_change;
  }
  else if (REGULATOR_MODE == 1){
    //ПИД
    motor_controllers[motor_index].current_pwm = computeRegulator(&regStates[motor_index], error, UPDATE_INTERVAL_MS);
  }  

//  Serial.print(error / RPM_MULTIPLIER);

  motor_controllers[motor_index].current_pwm = constrain(
    motor_controllers[motor_index].current_pwm,
    -MAX_PWM_VALUE,
    MAX_PWM_VALUE
  );

  //Serial.print(motor_controllers[motor_index].current_pwm);

//  Serial.print(',');
  // Управление выходами
  uint32_t pwm_value = abs(motor_controllers[motor_index].current_pwm);
  // if (flag_zero){
  //   pwm_value = 0;
  // }

  if(motor_controllers[motor_index].current_pwm < -PWM_DEADZONE){
    ledcWrite(motor_controllers[get_real_motor_idx(motor_index)].pwm_channel_a, 0);
    ledcWrite(motor_controllers[get_real_motor_idx(motor_index)].pwm_channel_b, pwm_value);
  }
  else if(motor_controllers[motor_index].current_pwm > PWM_DEADZONE){
    ledcWrite(motor_controllers[get_real_motor_idx(motor_index)].pwm_channel_a, pwm_value);
    ledcWrite(motor_controllers[get_real_motor_idx(motor_index)].pwm_channel_b, 0);
  }
  else{
    ledcWrite(motor_controllers[get_real_motor_idx(motor_index)].pwm_channel_a, 0);
    ledcWrite(motor_controllers[get_real_motor_idx(motor_index)].pwm_channel_b, 0);
  }
}

uint8_t get_real_motor_idx(uint8_t motor_index) {
  switch (motor_index){
    case 0:
      motor_index = 3;
      break;
    case 1:
      motor_index = 2;
      break;
    case 2:
      motor_index = 0;
      break;
    case 3:
      motor_index = 1;
      break;
  }
  return motor_index;
}

// Единая функция регулятора, работающая с конкретным состоянием
// Раюоатет в УМНОЖЕННОМ пространсвте
// Выход жедим на УМНОЖИТЕЛЬ - так сразу и переходим в пространсвто шима
int32_t computeRegulator(RegulatorState* regStates, int32_t error, int32_t dt) {
    // Реализация регулятора (например, ПИД)
    regStates->_integral += error * dt;
    regStates->_integral = constrain(regStates->_integral, -regStates->max_integral, regStates->max_integral);
    int32_t derivative = (error - regStates->prevError) / dt;
    regStates->prevError = error;

    int32_t _output = (KP * error + KI * regStates->_integral + KD * derivative) / RPM_MULTIPLIER;
    return _output;
}

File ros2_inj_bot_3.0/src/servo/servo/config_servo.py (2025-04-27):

offset_0 = -2
arm_positions = {
  
    0 : ([142-offset_0, 133, 130, 132, 0, 128, 42], 'init'),
    1 : ([142-offset_0-90, 133+75, 130-120, 132, 0, 128, 42],'search_qr'),
    2 : ([142-offset_0-45, 133+38, 130-60, 132, 0, 128, 42], 'interim_qr_direct'),
    3 : ([142-offset_0, 133+75, 130-120, 132, 0, 128, 42], 'direct_cam'),
    4 : ([142-offset_0-45, 133+75, 130-120, 132, 0, 128, 42], 'direct_45_cam'),
    5: ([142-offset_0, 133-75, 130-45, 132, 0, 128, 42], 'direct_long'),

    10: ([142-90-offset_0, 133, 130, 132, 1, 128, 42], 'search_fruit_pre'),
    11: ([142-90-offset_0, 133-100, 130+120, 132-115, 1, 128, 42], 'search_fruit'),

    23: ([142-90-offset_0, 133-50, 130+120, 132-115, 1, 128, 42], 'pre_knock_down_fruit'),
    12: ([142-offset_0-90, 133-80, 130+30, 132+35, 1, 128, 42], 'knock_down_fruit'),
    24: ([142-offset_0-90, 133-80, 130+10, 132-40, 1, 128, 42], 'after_knock_down_fruit'),
    
    13: ([142-offset_0-90, 133-80, 130+110, 132-102, 1, 128, 42], 'lower_pick0'),
    25: ([142-offset_0-90, 133-80, 130+100, 132-90, 1, 128, 42], 'lower_pick1'),
    26: ([142-offset_0-90, 133-80, 130+90, 132-80, 1, 128, 42], 'lower_pick2'),
    27: ([142-offset_0-90, 133-80, 130+80, 132-68, 1, 128, 42], 'lower_pick3'),
    28: ([142-offset_0-90, 133-80, 130+70, 132-60, 1, 128, 42], 'lower_pick3'),
    29: ([142-offset_0-90, 133-80, 130+60, 132-48, 1, 128, 42], 'lower_pick3'),
    30: ([142-offset_0-90, 133-80, 130+50, 132-33, 1, 128, 42], 'lower_pick3'),
    31: ([142-offset_0-90, 133-80, 130+38, 132-20, 1, 128, 42], 'lower_pick3'),
    32: ([142-offset_0-90, 133-80, 130+26, 132-5, 1, 128, 42], 'lower_pick3'),
    33: ([142-offset_0-90, 133-80, 130+15, 132+10, 1, 128, 42], 'lower_pick3'),
    #14: ([142-offset_0-90, 133-100, 130+75, 132-110, 1, 128, 42], 'lengthen_pick'),
    15: ([142-offset_0-90, 133-0, 130+40, 132+40, 1, 128, 42], 'up_pick'),
    34: ([142-offset_0-90, 133-0, 130+30, 132+10, 1, 128, 42], 'up_pick'),
    38: ([142-offset_0-135, 133+10, 130+20, 132+0, 1, 128, 42], 'turn_rigth_for_pick'),
    35: ([142-offset_0-135, 133-0, 130-25, 132-50, 1, 128, 42], 'up_pick'),
    36: ([142-offset_0-135, 133-0, 130+0, 132-30, 1, 28, 42], 'up_pick'),

    # 16: ([142-offset_0-90, 133+90, 130-120, 132, 1, 128, 42], 'throw_long'),
    
    17: ([142-offset_0-90, 133-30, 130+0, 132-30, 1, 28, 42], 'throw_short1'),
    37: ([142-offset_0-90, 133-60, 130-0, 132+30, 1, 28, 42], 'throw_short1'),
    39: ([142-offset_0-90, 133-90, 130+0, 132+30, 1, 28, 42], 'throw_short1'),
    40: ([142-offset_0-90, 133-90, 130+40, 132+20, 1, 28, 42], 'throw_short1'),
    41: ([142-offset_0-90, 133-90, 130+70, 132-10, 1, 28, 42], 'throw_short1'),
    42: ([142-offset_0-90, 133-90, 130+110, 132-50, 1, 28, 42], 'throw_short1'),
    43: ([142-offset_0-90, 133-90, 130+110, 132-40, 1, 28, 42], 'throw_short1'),
    44: ([142-offset_0-90, 133-90, 130+110, 132-30, 1, 28, 42], 'throw_short1'),
    45: ([142-offset_0-90, 133-90, 130+110, 132-20, 1, 28, 42], 'throw_short1'),
    46: ([142-offset_0-90, 133-90, 130+110, 132-10, 1, 28, 42], 'throw_short1'),
    47: ([142-offset_0-90, 133-90, 130+110, 132-5, 1, 28, 42], 'throw_short1'),
    48: ([142-offset_0-90, 133-90, 130+110, 132, 1, 28, 42], 'throw_short1'),
    49: ([142-offset_0-90, 133-90, 130+110, 132+5, 1, 28, 42], 'throw_short1'),
    50: ([142-offset_0-90, 133-90, 130+110, 132+10, 1, 28, 42], 'throw_short1'),
    51: ([142-offset_0-90, 133-90, 130+110, 132+15, 1, 28, 42], 'throw_short1'),
    52: ([142-offset_0-90, 133-90, 130+110, 132+20, 1, 28, 42], 'throw_short1'),
    53: ([142-offset_0-90, 133-90, 130+110, 132+25, 1, 28, 42], 'throw_short1'),
    54: ([142-offset_0-90, 133-90, 130+110, 132+30, 1, 28, 42], 'throw_short1'),
    55: ([142-offset_0-90, 133-90, 130+110, 132+35, 1, 28, 42], 'throw_short1'),
    56: ([142-offset_0-90, 133-90, 130+110, 132+40, 1, 28, 42], 'throw_short1'),

    60: ([142-90-offset_0, 133+30, 130-120, 132-18, 1, 128, 42], 'safe_border_short_pose'),
    # 61: ([142-90-offset_0, 133+70, 130-80, 132+10, 1, 128, 42], 'safe_border_short_pose'),
    # 62: ([142-90-offset_0, 133+50, 130-40, 132+10, 1, 128, 42], 'safe_border_short_pose'),
    63: ([142-90-offset_0, 133+30, 130-0, 132+10, 1, 128, 42], 'safe_border_short_pose'),    

    18: ([142-offset_0-45, 133-75, 130+35, 132, 1, 128, 42], 'turn_rigth_for_pick'),
    19: ([142-offset_0-90, 133, 130-45, 132, 0, 128, 42], 'safe_up_for_init_ang'),
    20: ([142-offset_0-90, 133-75, 130+120, 132, 1, 128, 42], 'search_fruit_pre_after_up_pick'),
    21: ([142-offset_0, 133-75, 130+35, 132, 1, 128, 42], 'turn_for_back_throw_short'),
    22: ([142-offset_0, 133+21, 130+120, 132, 1, 128, 42], 'throw_short_back'),

    #100 : ([142-offset_0, 133+50, 130-90, 132, 0, 128, 42], 'safety'),

    99: ([142-offset_0-120, 133, 130, 132, 1, 128, 42], 'throw_short_back'),


}

"""
для сбития из 11:
23-12-24-11

для взятия из 11
23-11-13-25-26-27-28-29-30-31-32-33-15-34-35-36

бросок взятого из 36
17-37-23-11
"""

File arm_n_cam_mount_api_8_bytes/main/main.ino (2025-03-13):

/*
   0 - основание руки
   1 .. 3 - звенья руки
   4 - схват
   5 - основание камеры
   6 - высота камеры

   Ораничения по мкс и углам указаны фактические (реальные).
   При этом на вход должны подаваться углы из дипазона без смещениея (0-255),
   а здесь добавляем смещение и корреткно переводим в мкс.

   Например у нулеового звена фактичсекий диапазон от 0 до 284,
   но принимаем 0-255 и добавляем оффсет 15 согласно таблице.
   Получем, например, для переданного угла 128 значение 143 - действительное среднее положение сервопривода.

   Для сервоприводов камеры всё немного иначе.
   Для сервпривода базы имеем диапазон от -87 до 87, а передам от 0 до 174

   Для отправки углов сначала получаем реальный угол переводом мкс,
   затем вычитаем из угла оффсет и переводим в byte.
   Проверка на байтовый диапазон фактически не трубется, так как мы не можем изначально подать угол больше байта.
*/

#include <ServoDriverSmooth.h>
#include <EEPROM.h>
#include <Wire.h>

#define IDX_Z 3
#define SAMPLES_Z 3
#define SAMPLE_Z_DELAY 2
//#define STAB_DELAY_Z 15
#define STEP_Z 6
//#define STEP_INC 30     // Увеличение шага при успехе
//#define STEP_DEC 15    // Уменьшение шага при неудаче

const byte servoNum = 7;
const uint16_t addr = 42;

ServoDriverSmooth servo[servoNum];

struct ServoSettings {
  int minMcs[servoNum] = {84, 116, 116, 116, 260, 135, 150};
  int maxMcs[servoNum] = {582, 542, 542, 542, 430, 525, 467};
  int minAng[servoNum] = {0, 0, 0, 0, 0, 42, 98};
  int maxAng[servoNum] = {284, 266, 260, 264, 1, 215, 218};
  // int offsetAng[servoNum] = {15, 6, 3, 5, 0, 0, 0};
  int armAcc = 80;
  int armSpeed = 1080;
  int camAcc = 480;
  int camSpeed = 1080;
};
ServoSettings servoSettings;

struct ServoPosAng {
  int pos[servoNum] = {128, 128, 128, 128, 0, 87, 90};
  byte currPos[servoNum] = {0, 0, 0, 0, 0, 0, 0};
};
ServoPosAng servoPosAng, prevServoPosAng;

struct AutoServo{
  int linkDefVal = 128;
  //int init_ang, plus_ang, minus_ang;
  int acc[3] = {0, 0, 0};
  //uint8_t count_init, count_plus, count_minus;
  uint8_t count[3] = {0,0,0};
};
AutoServo autoServo;

uint32_t servoSendTimer = 0;
const uint32_t servoSendPeriod = 21;

const int MPU = 0x68;
int accX, accY, accZ;
bool isPlus;

uint32_t autoServoUpdateTImer = 0;
const uint32_t autoServoUpdatePeriod = 50;

bool i2cBusy = true;

void updateValCount(int* val, uint8_t* counter){
  counter += 1;
  val += mpuReadZ();
}

int mpuReadZ(){
  Wire.beginTransmission(MPU);
  Wire.write(0x3B); // Start with register 0x3B (ACCEL_XOUT_H)
  Wire.endTransmission(false);
  Wire.requestFrom(MPU, 6, true); // Read 6 registers total, each axis value is stored in 2 registers
  //For a range of +-2g, we need to divide the raw values by 16384, according to the datasheet
  accX = (Wire.read() << 8 | Wire.read()); // X-axis value
  accY = (Wire.read() << 8 | Wire.read()); // Y-axis value
  accZ = (Wire.read() << 8 | Wire.read()); // Z-axis value
  Wire.endTransmission(true);
  return accZ;
}

//// Функция усреднения и сглаживания az
//int getAvgAZ() {
//  int sum = 0;
//  for (uint8_t i = 0; i < SAMPLES_Z; i++) {
//    sum += mpuReadZ(); // Замените A0 на нужный пин
//    delay(SAMPLE_Z_DELAY);
//  }
//  int az = sum / SAMPLES_Z;
//  return az;
//}

uint8_t fletcher8(uint8_t *data, size_t len) {
  uint8_t sum1 = 0;
  uint8_t sum2 = 0;
  for (size_t i = 0; i < len; i++) {
    sum1 = (sum1 + data[i]) % 255;
    sum2 = (sum2 + sum1) % 255;
    //Serial.println(data[i]);
  }
  return (sum1 + sum2) % 255;
}

int anglesToMcs(int angles, byte idx) {
  int from_a_min = servoSettings.minAng[idx];
  int from_a_max = servoSettings.maxAng[idx];
  int to_mcs_min = servoSettings.minMcs[idx];
  int to_mcs_max = servoSettings.maxMcs[idx];
  return map(angles, from_a_min, from_a_max, to_mcs_min, to_mcs_max);
}

int mcsToAngle(int mcs, byte idx) {
  int from_mcs_min = servoSettings.minMcs[idx];
  int from_mcs_max = servoSettings.maxMcs[idx];
  int to_a_min = servoSettings.minAng[idx];
  int to_a_max = servoSettings.maxAng[idx];
  return constrain(map(mcs, from_mcs_min, from_mcs_max, to_a_min, to_a_max), 0, 255);
}

void setup() {
  Serial.begin(115200);
  EEPROM.get(addr, prevServoPosAng);
  
  Wire.begin();
  Wire.beginTransmission(MPU);       // Start communication with MPU6050 // MPU=0x68
  Wire.write(0x6B);                  // Talk to the register 6B
  Wire.write(0x00);
  Wire.endTransmission(true);

  Serial.println(prevServoPosAng.pos[0]);

  servo[0].attach(0, servoSettings.minMcs[0], servoSettings.maxMcs[0]);
  servo[0].writeMicroseconds(anglesToMcs(prevServoPosAng.pos[0], 0));
  servo[0].setAutoDetach(false);
  servo[0].setSpeed(servoSettings.armSpeed);
  servo[0].setAccel(servoSettings.armAcc);

  servo[1].attach(1, servoSettings.minMcs[1], servoSettings.maxMcs[1]);
  servo[1].writeMicroseconds(anglesToMcs(prevServoPosAng.pos[1], 1));
  servo[1].setAutoDetach(false);
  servo[1].setSpeed(servoSettings.armSpeed);
  servo[1].setAccel(servoSettings.armAcc);

  servo[2].attach(2, servoSettings.minMcs[2], servoSettings.maxMcs[2]);
  servo[2].writeMicroseconds(anglesToMcs(prevServoPosAng.pos[2], 2));
  servo[2].setAutoDetach(false);
  servo[2].setSpeed(servoSettings.armSpeed);
  servo[2].setAccel(servoSettings.armAcc);

  servo[3].attach(3, servoSettings.minMcs[3], servoSettings.maxMcs[3]);
  servo[3].writeMicroseconds(anglesToMcs(prevServoPosAng.pos[3], 3));
  servo[3].setAutoDetach(false);
  servo[3].setSpeed(servoSettings.armSpeed);
  servo[3].setAccel(480);

  servo[4].attach(4, servoSettings.minMcs[4], servoSettings.maxMcs[4]);
  servo[4].writeMicroseconds(anglesToMcs(prevServoPosAng.pos[4], 4));
  servo[4].setAutoDetach(false);
  servo[4].setSpeed(servoSettings.armSpeed);
  servo[4].setAccel(servoSettings.armAcc);

  servo[5].attach(8, servoSettings.minMcs[5], servoSettings.maxMcs[5]);
  servo[5].writeMicroseconds(anglesToMcs(prevServoPosAng.pos[5], 5));
  servo[5].setAutoDetach(false);
  servo[5].setSpeed(servoSettings.camSpeed);
  servo[5].setAccel(servoSettings.camAcc);

  servo[6].attach(9, servoSettings.minMcs[6], servoSettings.maxMcs[6]);
  servo[6].writeMicroseconds(anglesToMcs(prevServoPosAng.pos[6], 6));
  servo[6].setAutoDetach(false);
  servo[6].setSpeed(servoSettings.camSpeed);
  servo[6].setAccel(servoSettings.camAcc);

}
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

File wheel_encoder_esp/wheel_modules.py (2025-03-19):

import serial
import struct

# SERIAL_PORT = "/dev/ttyUSB0"  # Пример для Linux, для Windows используйте "COMx"
# BAUD_RATE = 115200

# def fletcher16(data):
#     sum1 = 0
#     sum2 = 0
#     for byte in data:
#         sum1 = (sum1 + byte) % 255
#         sum2 = (sum2 + sum1) % 255
#     return (sum2 << 8) | sum1

# try:
#     ser = serial.Serial(SERIAL_PORT, BAUD_RATE, timeout=0.1)
#     print(f"Connected to {SERIAL_PORT}")
# except Exception as e:
#     print(f"Port error: {e}")
#     exit()

# buffer = bytearray()
# STATE_SEARCH = 0
# STATE_READ_DATA = 1
# state = STATE_SEARCH
# expected_length = 19  # 1 (S) + 16 (4 float) + 2 (checksum)

# while True:
#     try:
#         # Чтение данных порциями
#         data = ser.read(1)
#         if data:
#             buffer.extend(data)
        
#         # Обработка буфера
#         while True:
#             if state == STATE_SEARCH:
#                 # Поиск стартового байта 'S' (0x53)
#                 start_pos = buffer.find(b'S')
#                 if start_pos == -1:
#                     buffer.clear()  # Нет 'S' - очистка буфера
#                     break
                
#                 # Переходим в режим чтения данных
#                 buffer = buffer[start_pos:]  # Обрезаем все до 'S'
#                 state = STATE_READ_DATA

#             elif state == STATE_READ_DATA:
#                 if len(buffer) < expected_length:
#                     break  # Ждем больше данных
                
#                 # Извлекаем пакет
#                 packet = buffer[:expected_length]
#                 buffer = buffer[expected_length:]
                
#                 # Проверка контрольной суммы
#                 calc_csum = fletcher16(packet[:17])
#                 recv_csum = struct.unpack_from('<H', packet, 17)[0]
                
#                 if calc_csum != recv_csum:
#                     print("Checksum error! Resyncing...")
#                     state = STATE_SEARCH
#                     continue
                
#                 # Распаковка данных (little-endian)
#                 speeds = struct.unpack_from('<4f', packet, 1)
#                 print(f"Speeds (FL, RL, FR, RR): {speeds}")
                
#                 state = STATE_SEARCH  # Возврат к поиску

#     except KeyboardInterrupt:
#         print("\nExiting...")
#         break
#     except Exception as e:
#         print(f"Error: {e}")
#         state = STATE_SEARCH  # Сброс состояния при ошибке

# ser.close()

def fletcher16(data):
    sum1 = 0
    sum2 = 0
    for byte in data:
        sum1 = (sum1 + byte) % 255
        sum2 = (sum2 + sum1) % 255
    return (sum2 << 8) | sum1

def create_byte_array(speeds):
    if len(speeds) != 4:
        raise ValueError("Must be 4 speeds")
    
    data = bytearray(b'S')
    for speed in speeds:
        if not (-2147483648 <= speed <= 2147483647):
            raise ValueError("Must be int32 type")
        data.extend(speed.to_bytes(4, byteorder='little', signed=True))

    checksum = fletcher16(data)
    data.extend(checksum.to_bytes(2, byteorder='big'))

    return data

def send_to_serial(ser, speeds):
    data = create_byte_array(speeds)
    ser.write(data)
    ser.flush()


def fletcher16(data):
    sum1 = 0
    sum2 = 0
    for byte in data:
        sum1 = (sum1 + byte) % 255
        sum2 = (sum2 + sum1) % 255
    return (sum2 << 8) | sum1


def parse_packet(packet):
    if len(packet) != 19:
        return None
    if packet[0] != ord('S'):
        return None
    
    # Проверка контрольной суммы (первые 17 байт)
    received_checksum = (packet[17] << 8) | packet[18]
    calculated_checksum = fletcher16(packet[:17])
    
    if received_checksum != calculated_checksum:
        return None
    
    # Парсинг 4-байтовых значений (little-endian)
    rpms = []
    for i in range(4):
        start_idx = 1 + i*4
        value_bytes = packet[start_idx:start_idx+4]
        value = int.from_bytes(value_bytes, byteorder='little', signed=True)
        rpms.append(value)
    
    return rpms

def main_receive_example():
    START_BYTE = ord('S')
    PACKET_LENGTH = 19
    ser = serial.Serial('/dev/ttyUSB0', 115200, timeout=1)
    buffer = bytearray()

    while True:
        # Чтение одного байта за итерацию
        while ser.in_waiting > 0:
            byte = ser.read(1)
            buffer.append(byte[0])

            # Поиск и обработка полных пакетов
            while True:
                # Поиск стартового байта
                start_pos = buffer.find(START_BYTE.to_bytes(1, 'big'))
                
                if start_pos == -1:
                    # Нет стартового байта - очищаем буфер
                    buffer.clear()
                    break
                
                if start_pos > 0:
                    # Удаляем мусор до стартового байта
                    del buffer[:start_pos]
                
                if len(buffer) < PACKET_LENGTH:
                    # Не хватает данных для полного пакета
                    break
                
                # Извлекаем потенциальный пакет
                packet = buffer[:PACKET_LENGTH]
                del buffer[:PACKET_LENGTH]
                
                # Парсим и проверяем
                parsed = parse_packet(packet)
                if parsed is not None:
                    print("Received RPMs:", parsed)
                else:
                    print("Invalid packet received")

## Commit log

2025-01-24 add some models; edit api and example
    [arm_cam.stl, bin_cam.stl]
2025-01-24 init wheel encoder
2025-01-25 big commit: edit arm api, create some test script for pca9658
    [display.stl, Лист Microsoft Excel.xlsx]
2025-01-25 edit servo settings
2025-01-27 switch from stm to esp
    [bin_cam.stl, Лист Microsoft Excel.xlsx]
2025-02-03 init newton-raphson
    [calib_angles.xlsx, Лист Microsoft Excel.xlsx]
2025-02-04 edit angles range for ard main
    [calib_angles.xlsx]
2025-02-06 edit servo control, set up send n receive, edit range for 4th servo
    [calib_angles.xlsx]
2025-02-14 add lidar test script
2025-02-15 try to connect to lidar
2025-02-15 some lidar data views
2025-02-17 add medianizer lidar data
2025-02-20 init camera package, rename custom modules
2025-02-22 add test script for esp wheel control
2025-02-23 finish camera mvp
2025-02-24 init servo pkg, edit servo arduino firmware
2025-02-24 write recieve node for servo pkg; add some libraries for arm driver
2025-02-24 create udev for lidar, servo; update pkgs description
2025-02-25 add desc for wheel enc; edit main esp script for enc pins
2025-02-25 pre-rename pwm pins
2025-02-25 reverse to 1000 random collect data
    [ikp.py, newton_raphson.py]
2025-02-25 set test pwm values
2025-02-25 add cameras saving video
2025-02-25 sconfig camera package
2025-02-25 config camera package
2025-02-25 init wheel pkg
2025-02-27 edit test esp32 receiver
2025-02-27 create get frames from mp4
2025-02-28 edit servo range, servo set up
2025-03-07 set up keyboard servo
2025-03-14 move auto servo to arduino
2025-03-16 edit auto servo imu move
    [calib_angles.xlsx]
2025-03-18 create one thread exchange servo data
2025-03-18 update servo drivers firmware
2025-03-18 refac(fuck_)wheel pkg
2025-03-19 add esp wheel script
2025-03-19 update wheel exchange data
2025-03-19 final wheel key control
2025-03-20 edit driver regulator
2025-03-31 refactoring, add lib, fix fps arm
    [checking_wheels_rotare.py, play_audio.py, twist_to_rpm.py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]
2025-04-01 add arm gray frame publisher
2025-04-02 WIP: checkout before lidar movement
2025-04-02 WIP: editing lidar data
2025-04-02 fix nan inf problems lidar data
2025-04-03 WIP: fix some bugs
    [lut_control.py]
2025-04-05 WIP: wheel over heat
2025-04-08 test old cam arm
2025-04-08 add universal letter servo arm commands
2025-04-08 return correct mode
    [magnets.stl]
2025-04-09 WIP: try update main servo firmware
2025-04-13 init common servo config
2025-04-13 WIP: init arm sactions
2025-04-14 update pid
2025-04-14 switch to async thread
2025-04-14 add fruit gripper
    [box_maxi.stl, box_mini.stl]
2025-04-16 edit acc servo err
2025-04-16 add servo actions
2025-04-16 wip: test pid
2025-04-16 set up boreder regulator
2025-04-16 wip trouble 3rd servo
2025-04-16 add uopgrade short throw
    [box_maxi_stable.stl]
2025-04-19 add pick up and throw short operations
    [config_servo.py, data_exchange.py, one_thread_send_receive.py]
2025-04-23 success home move test
    [labels.csv]
2025-04-25 edit arm settings
    [labels.csv, model.ncnn.param, results.csv]
2025-04-25 init neural space
    [labels.csv, model.ncnn.param, results.csv]
2025-04-26 finish prepair zero day
    [labels.csv]
2025-04-27 wip: before first attempt
    [model.ncnn.param]
2025-11-23 fix eventN bug
    [box_maxi_reinforced.stl]
